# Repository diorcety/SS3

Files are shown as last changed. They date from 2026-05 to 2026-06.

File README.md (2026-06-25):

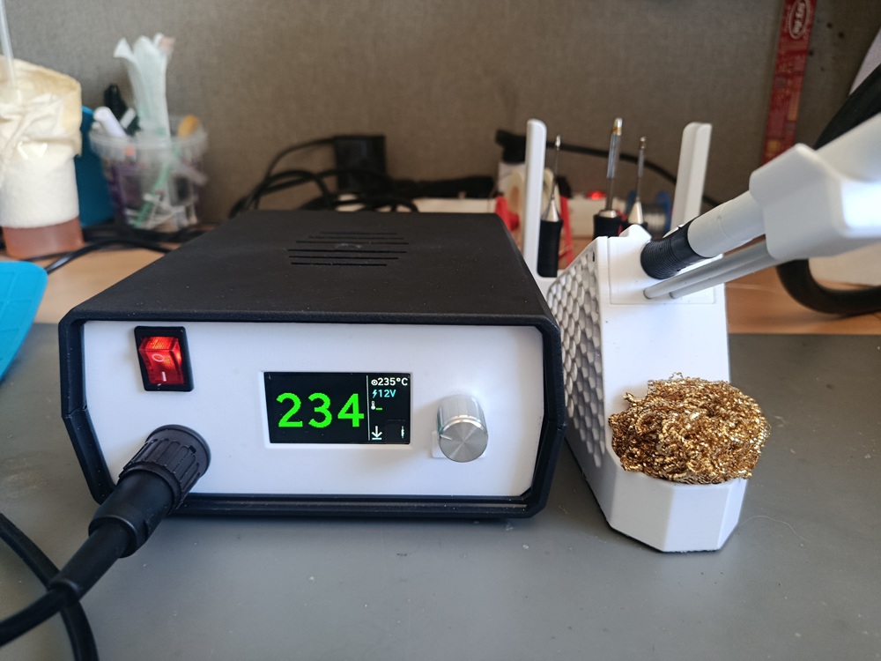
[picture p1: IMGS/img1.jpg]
SS3 Solder Station


# SS3 — Solder Station 3

A DIY Weller-compatible soldering station controller, inspired by the [kair.us Weller WMRP and WMRT compatible soldering station](http://kair.us/projects/weller/index.html).

## Overview

SS3 is a two-board redesign of the kair.us open-source solder station. The key differences from the original are:

- **Transformer-based power supply** instead of SMPS — cleaner, simpler, lower EMI
- **Native 12V and 24V tip support** — handle type is identified by reading a resistor inside the handle via a voltage divider (510Ω for WXUP, 1kΩ for WMRP, 2kΩ for WMRT)
- **MSPM0G1507SRHBR MCU** (Texas Instruments) replacing the PIC16F1788
- **Dual MOSFET back-to-back switching stage** acting as a solid-state triac with minimal conduction losses

## Hardware — Two Boards

### MCU / Display Board
Handles all control logic, ADC measurements, and user interface.

- MSPM0G1507SRHBR microcontroller (default)
  - MSPM0G1505SRHBR can be used for 7-segment display builds
  - MSPM0G1506SRHBR can be used for TFT display builds
  - Switching variant requires updating `device_linker.cmd`
- Onboard ADC for thermocouple sensing (cold-junction compensation is handled inside the handle itself)
- Display support:
  - 4× 7-segment LED display
  - 1.9" TFT color screen

### Power Board
Drives the resistive heating element of the tip.

- Four dual N-MOSFET ICs (8 MOSFETs total), one per heating channel: two channels (left/right) × two voltages (12V/24V), each pair wired back-to-back
- Each pair acts as a solid-state triac equivalent, covering both 12V and 24V channels
- Lower switching losses compared to a traditional triac

## Tip Compatibility

Compatible with Weller active tips using an integrated heater and thermocouple:

- **WMRP** — soldering pen (12V)
- **WMRT** — desoldering tweezers (12V)
- **WXUP** — soldering pen (24V)

## Directory Structure

```
SS3/
├── 3D/       — Stands and handle models (12V and 24V variants; no enclosure provided)
├── PCBS/     — KiCad / Gerber files for both boards, plus KiCad conversions of the
│              original kair.us WMRP and WMRT boards (including mirrored variant for
│              mirrored jack barrels)
├── SIMS/     — LTSpice simulations: zero-cross detection, 3.6V SMPS from half-wave
│              rectifier, and back-to-back N-MOSFET triac equivalent
└── SS3/      — Firmware source (CMake project)
```

## Credits

Based on the open-source [Weller WMRP and WMRT compatible soldering station](http://kair.us/projects/weller/index.html) by kair.us.

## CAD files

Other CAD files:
3D/Stand.f3d
3D/WMRP Handle.f3d
3D/WXUP Handle.f3d

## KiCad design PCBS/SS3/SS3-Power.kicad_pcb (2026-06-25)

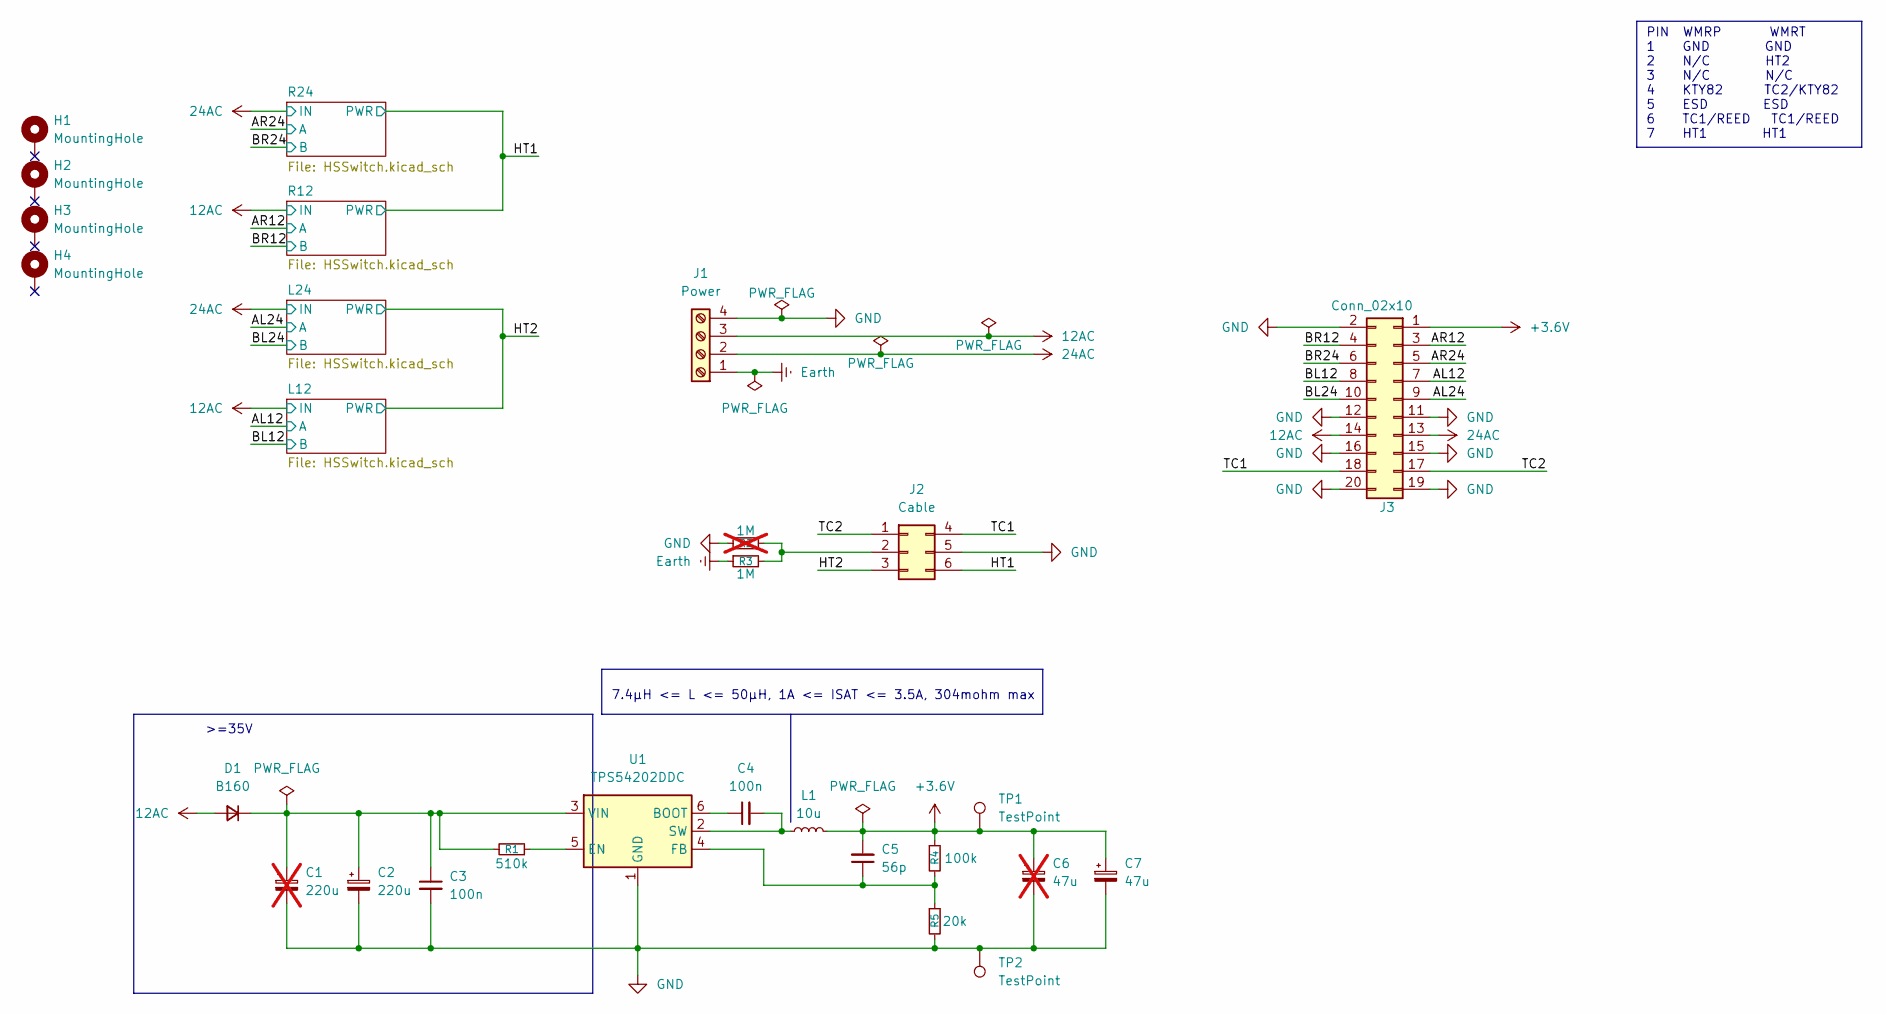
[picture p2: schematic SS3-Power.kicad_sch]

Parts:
C1: 220u; CP_Elec_10x10.5; not fitted
C2: 220u; CP_Elec_10x10.5
C3, C4: 100n; C_0402_1005Metric
C5: 56p; C_0402_1005Metric
C6: 47u; CP_Elec_6.3x5.9; not fitted
C7: 47u; CP_Elec_6.3x5.9
D1: B160; D_SMB
H1, H2, H3, H4: MountingHole; MountingHole_2mm_M1.8_Pad
J1: Power; TerminalBlock_Phoenix_PT-1,5-4-3.5-H_1x04_P3.50mm_Horizontal
J2: Cable; 10127720-061LF
J3: Conn_02x10; BF030-20A-B1-0360
L1: 10u; L_Chilisin_BWVS00606045
R1: 510k; R_0402_1005Metric
R2: 1M; R_0402_1005Metric; not fitted
R3: 1M; R_0402_1005Metric
R4: 100k; R_0402_1005Metric
R5: 20k; R_0402_1005Metric
TP1, TP2: TestPoint; TestPoint_THTPad_D2.0mm_Drill1.0mm
U1: TPS54202DDC; SOT-23-6

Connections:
12AC: D1.2 (A), J1.3, J3.14; also elsewhere on the board
24AC: J1.2, J3.13; also elsewhere on the board
+3.6V: C5.2, C6.1, C7.1, J3.1, L1.2, R4.1, TP1.1 (1_1)
/AL12: J3.7; also elsewhere on the board
/AL24: J3.9; also elsewhere on the board
/AR12: J3.3; also elsewhere on the board
/AR24: J3.5; also elsewhere on the board
/BL12: J3.8; also elsewhere on the board
/BL24: J3.10; also elsewhere on the board
/BR12: J3.4; also elsewhere on the board
/BR24: J3.6; also elsewhere on the board
/HT1: J2.6; also elsewhere on the board
/HT2: J2.3; also elsewhere on the board
/TC1: J2.4, J3.18
/TC2: J2.1, J3.17
Earth: J1.1, R3.1
GND: C1.2, C2.2, C3.2, C6.2, C7.2, J1.4, J2.5, J3.2, J3.11, J3.12, J3.15, J3.16, J3.19, J3.20, R2.2, R5.2, TP2.1 (1_1), U1.1 (GND); also elsewhere on the board
unnamed: C1.1, C2.1, C3.1, D1.1 (K), R1.2, U1.3 (VIN)
unnamed: J2.2, R2.1, R3.2
unnamed: C4.1, U1.6 (BOOT)
unnamed: R1.1, U1.5 (EN)
unnamed: C5.1, R4.2, R5.1, U1.4 (FB)
unnamed: C4.2, L1.1, U1.2 (SW)

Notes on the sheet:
PIN WMRP WMRT 1 GND GND 2 N/C HT2 3 N/C N/C 4 KTY82 TC2/KTY82 5 ESD ESD 6 TC1/REED TC1/REED 7 HT1 HT1
>=35V
7.4μH <= L <= 50μH, 1A <= ISAT <= 3.5A, 304mohm max

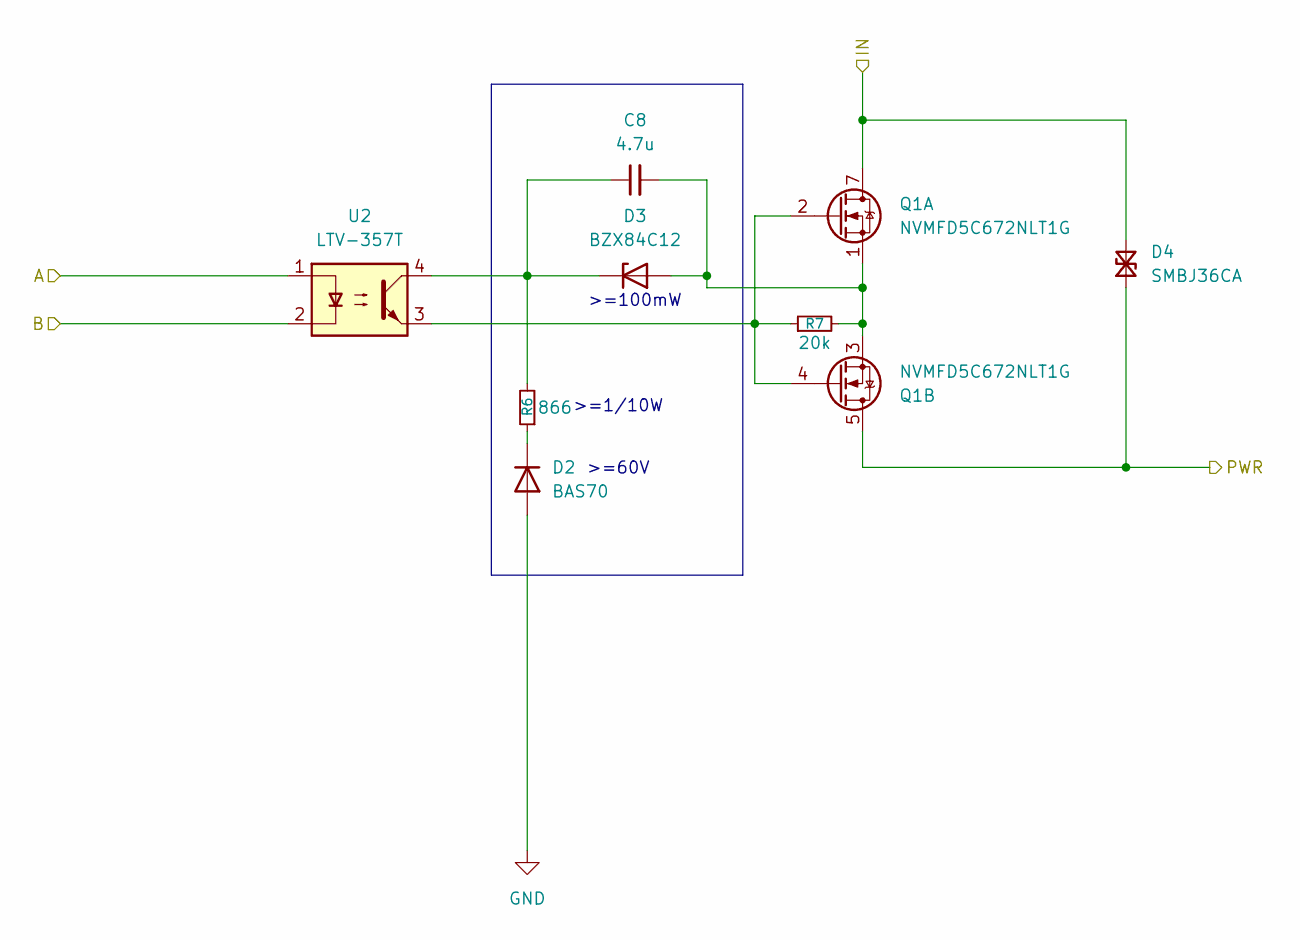
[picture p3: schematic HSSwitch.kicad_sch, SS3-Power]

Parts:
C8: 4.7u; C_0805_2012Metric
D2: BAS70; SOT-23
D3: BZX84C12; SOT-23
D4: SMBJ36CA; D_SMB
Q1: NVMFD5C672NLT1G; Mouser Part Number 863-NVMFD5C672NLT1G
R6: 866; R_0805_2012Metric
R7: 20k; R_0402_1005Metric
U2: LTV-357T; SO-4_4.4x3.6mm_P2.54mm

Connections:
24AC: D4.2 (A2), Q1.7, Q1.8 (D), Q1.9 (D), Q1.10 (D), Q1.11 (D); also elsewhere on the board
/AR24: U2.1; also elsewhere on the board
/BR24: U2.2; also elsewhere on the board
/HT1: D4.1 (A1), Q1.5, Q1.6 (D), Q1.12 (D), Q1.13 (D), Q1.14 (D); also elsewhere on the board
GND: D2.1 (A); also elsewhere on the board
unnamed: D2.3 (K), R6.1
unnamed: C8.2, D3.1 (A), Q1.1, Q1.3, R7.2
unnamed: C8.1, D3.3 (K), R6.2, U2.4
unnamed: Q1.2, Q1.4, R7.1, U2.3

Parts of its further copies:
C9, C10, C11: 4.7u; C_0805_2012Metric
D5, D8, D11: BAS70; SOT-23
D6, D9, D12: BZX84C12; SOT-23
D7, D10, D13: SMBJ36CA; D_SMB
Q2, Q3, Q4: NVMFD5C672NLT1G; Mouser Part Number 863-NVMFD5C672NLT1G
R8, R10, R12: 866; R_0805_2012Metric
R9, R11, R13: 20k; R_0402_1005Metric
U3, U4, U5: LTV-357T; SO-4_4.4x3.6mm_P2.54mm

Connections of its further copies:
12AC: D7.2 (A2), D13.2 (A2), Q2.7, Q2.8 (D), Q2.9 (D), Q2.10 (D), Q2.11 (D), Q4.7, Q4.8 (D), Q4.9 (D), Q4.10 (D), Q4.11 (D); also elsewhere on the board
24AC: D10.2 (A2), Q3.7, Q3.8 (D), Q3.9 (D), Q3.10 (D), Q3.11 (D); also elsewhere on the board
/AL12: U5.1; also elsewhere on the board
/AL24: U4.1; also elsewhere on the board
/AR12: U3.1; also elsewhere on the board
/BL12: U5.2; also elsewhere on the board
/BL24: U4.2; also elsewhere on the board
/BR12: U3.2; also elsewhere on the board
/HT1: D7.1 (A1), Q2.5, Q2.6 (D), Q2.12 (D), Q2.13 (D), Q2.14 (D); also elsewhere on the board
/HT2: D10.1 (A1), D13.1 (A1), Q3.5, Q3.6 (D), Q3.12 (D), Q3.13 (D), Q3.14 (D), Q4.5, Q4.6 (D), Q4.12 (D), Q4.13 (D), Q4.14 (D); also elsewhere on the board
GND: D5.1 (A), D8.1 (A), D11.1 (A); also elsewhere on the board
unnamed: D5.3 (K), R8.1
unnamed: C9.2, D6.1 (A), Q2.1, Q2.3, R9.2
unnamed: C9.1, D6.3 (K), R8.2, U3.4
unnamed: D8.3 (K), R10.1
unnamed: C10.2, D9.1 (A), Q3.1, Q3.3, R11.2
unnamed: C10.1, D9.3 (K), R10.2, U4.4
unnamed: D11.3 (K), R12.1
unnamed: C11.2, D12.1 (A), Q4.1, Q4.3, R13.2
unnamed: C11.1, D12.3 (K), R12.2, U5.4
unnamed: Q2.2, Q2.4, R9.1, U3.3
unnamed: Q3.2, Q3.4, R11.1, U4.3
unnamed: Q4.2, Q4.4, R13.1, U5.3

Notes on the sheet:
>=100mW
>=60V
>=1/10W

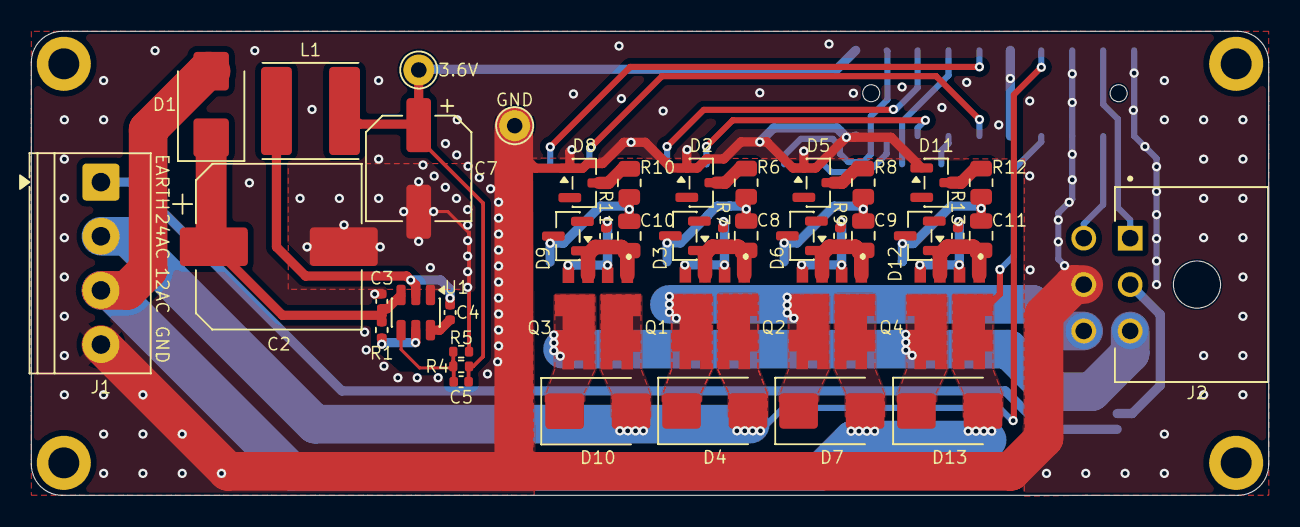
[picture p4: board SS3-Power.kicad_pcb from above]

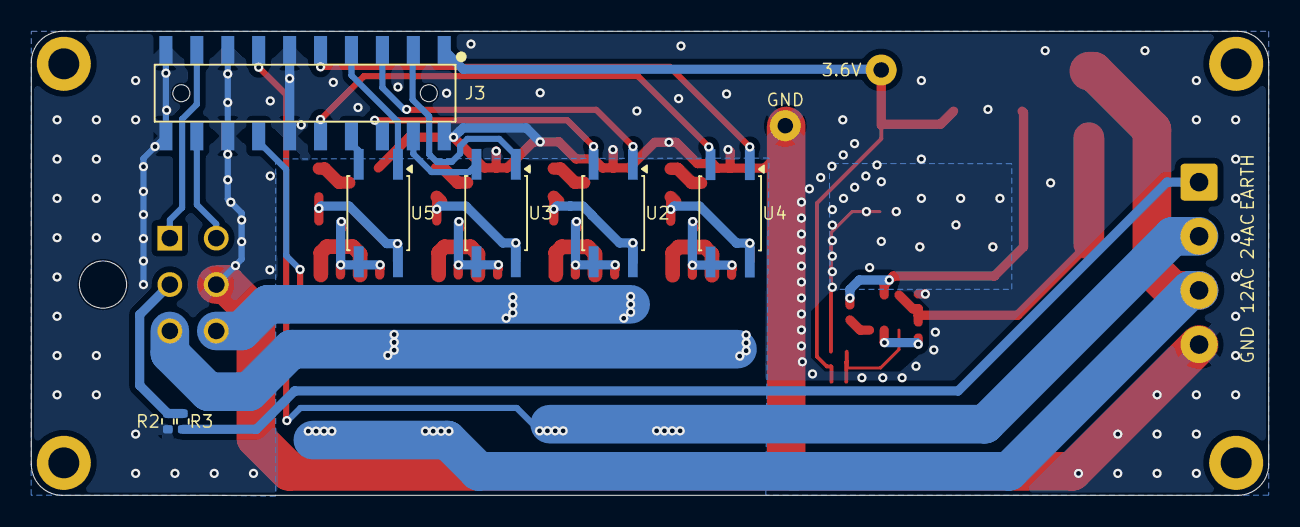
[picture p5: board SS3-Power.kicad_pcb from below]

Board: 2 copper layers, 80.0 x 30.0 mm, 54 parts (7 on the bottom side), 39 nets.

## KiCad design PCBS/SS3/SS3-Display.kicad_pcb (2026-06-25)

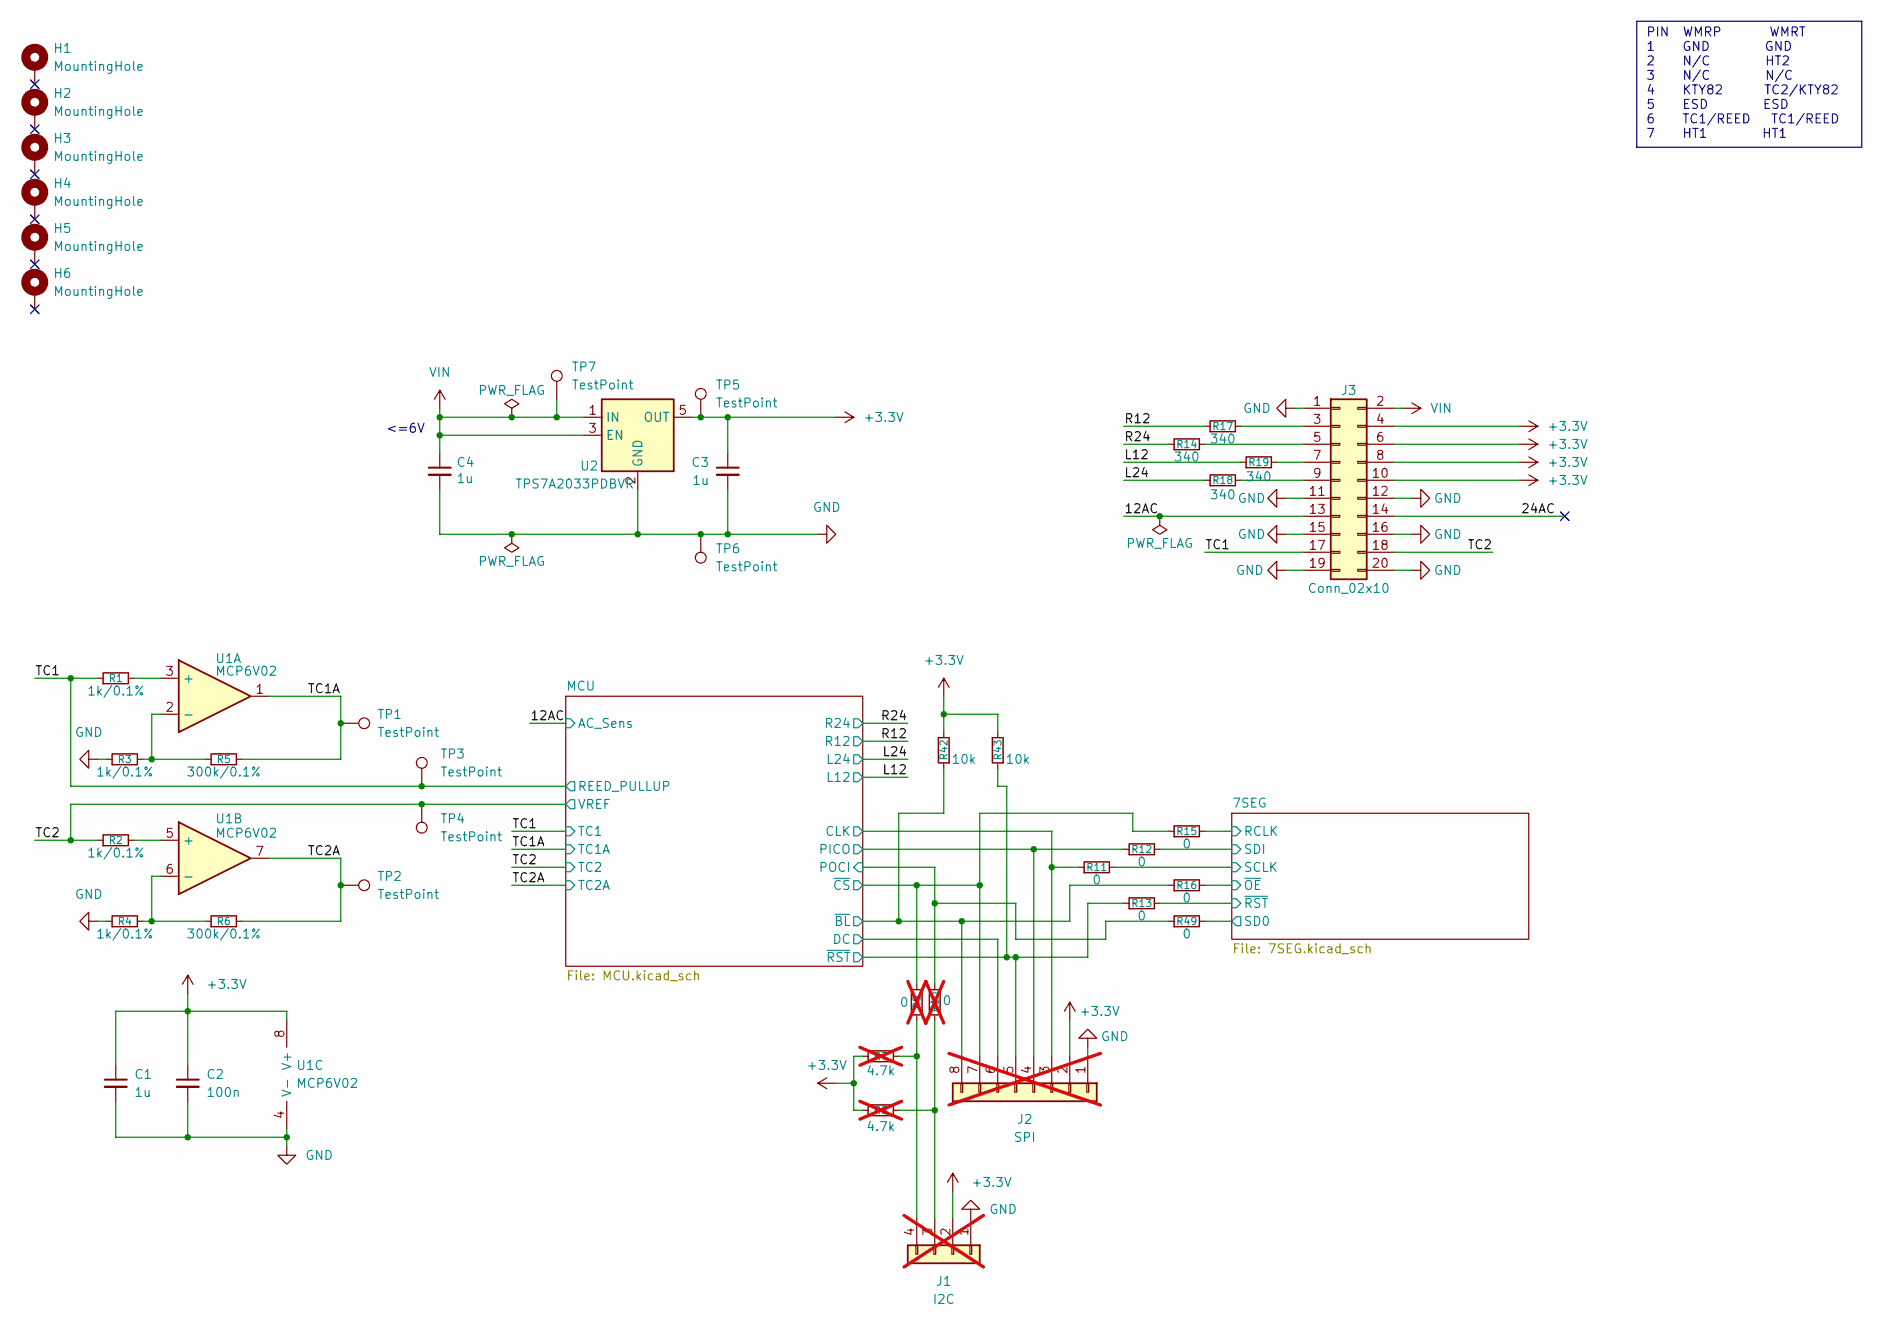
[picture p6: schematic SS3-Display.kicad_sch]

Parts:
C1, C3, C4: 1u; C_0402_1005Metric
C2: 100n; C_0402_1005Metric
H1, H2, H3, H4, H5, H6: MountingHole; MountingHole_2mm_M1.8_Pad
J1: I2C; PinHeader_1x04_P2.54mm_Vertical; not fitted
J2: SPI; PinHeader_1x08_P2.54mm_Vertical; not fitted
J3: Conn_02x10; BF100-20-A-D-1-0640
R1, R2, R3, R4: 1k/0.1%; R_0402_1005Metric
R5, R6: 300k/0.1%; R_0402_1005Metric
R7, R8: 4.7k; R_0402_1005Metric; not fitted
R9, R10: 0; R_0402_1005Metric; not fitted
R11, R12, R13, R15, R16, R49: 0; R_0402_1005Metric
R14, R17, R18, R19: 340; R_0402_1005Metric
R42, R43: 10k; R_0402_1005Metric
TP1, TP2, TP3, TP4, TP5, TP6, TP7: TestPoint; TestPoint_THTPad_D2.0mm_Drill1.0mm
U1: MCP6V02; SOIC-8_3.9x4.9mm_P1.27mm
U2: TPS7A2033PDBVR; SOT-23-5

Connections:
+3.3V: C1.1, C2.1, C3.1, J1.2, J2.2, J3.4, J3.6, J3.8, J3.10, R7.2, R8.2, R42.2, R43.2, TP5.1 (1_1), U1.8 (V+), U2.5 (OUT); also elsewhere on the board
/7SEG/RCLK: R15.2; also elsewhere on the board
/7SEG/SCLK: R11.2; also elsewhere on the board
/7SEG/SD0: R49.2; also elsewhere on the board
/7SEG/SDI: R12.2; also elsewhere on the board
/7SEG/~OE: R16.2; also elsewhere on the board
/7SEG/~RST: R13.2; also elsewhere on the board
/12AC: J3.13; also elsewhere on the board
/24AC: J3.14
/L12: R19.1; also elsewhere on the board
/L24: R18.1; also elsewhere on the board
/MCU/CLK: J2.3, R11.1; also elsewhere on the board
/MCU/DC: J2.6; also elsewhere on the board
/MCU/PICO: J2.4, R12.1; also elsewhere on the board
/MCU/POCI: R10.1, R49.1; also elsewhere on the board
/MCU/~BL: J2.8, R16.1, R42.1; also elsewhere on the board
/MCU/~CS: J2.7, R9.1, R15.1; also elsewhere on the board
/MCU/~RST: J2.5, R13.1, R43.1; also elsewhere on the board
/R12: R17.1; also elsewhere on the board
/R24: R14.1; also elsewhere on the board
/TC1: J3.17, R1.1, TP3.1 (1_1); also elsewhere on the board
/TC1A: R5.2, TP1.1 (1_1), U1.1; also elsewhere on the board
/TC2: J3.18, R2.1, TP4.1 (1_1); also elsewhere on the board
/TC2A: R6.2, TP2.1 (1_1), U1.7; also elsewhere on the board
GND: C1.2, C2.2, C3.2, C4.2, J1.1, J2.1, J3.1, J3.11, J3.12, J3.15, J3.16, J3.19, J3.20, R3.1, R4.1, TP6.1 (1_1), U1.4 (V-), U2.2 (GND); also elsewhere on the board
unnamed: J1.3, R8.1, R10.2
unnamed: J1.4, R7.1, R9.2
unnamed: J3.3, R17.2
unnamed: J3.5, R14.2
unnamed: J3.7, R19.2
unnamed: J3.9, R18.2
unnamed: R1.2, U1.3 (+)
unnamed: R3.2, R5.1, U1.2 (-)
unnamed: R2.2, U1.5 (+)
unnamed: R4.2, R6.1, U1.6 (-)
VIN: C4.1, J3.2, TP7.1 (1_1), U2.1 (IN), U2.3 (EN)

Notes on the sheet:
<=6V
PIN WMRP WMRT 1 GND GND 2 N/C HT2 3 N/C N/C 4 KTY82 TC2/KTY82 5 ESD ESD 6 TC1/REED TC1/REED 7 HT1 HT1

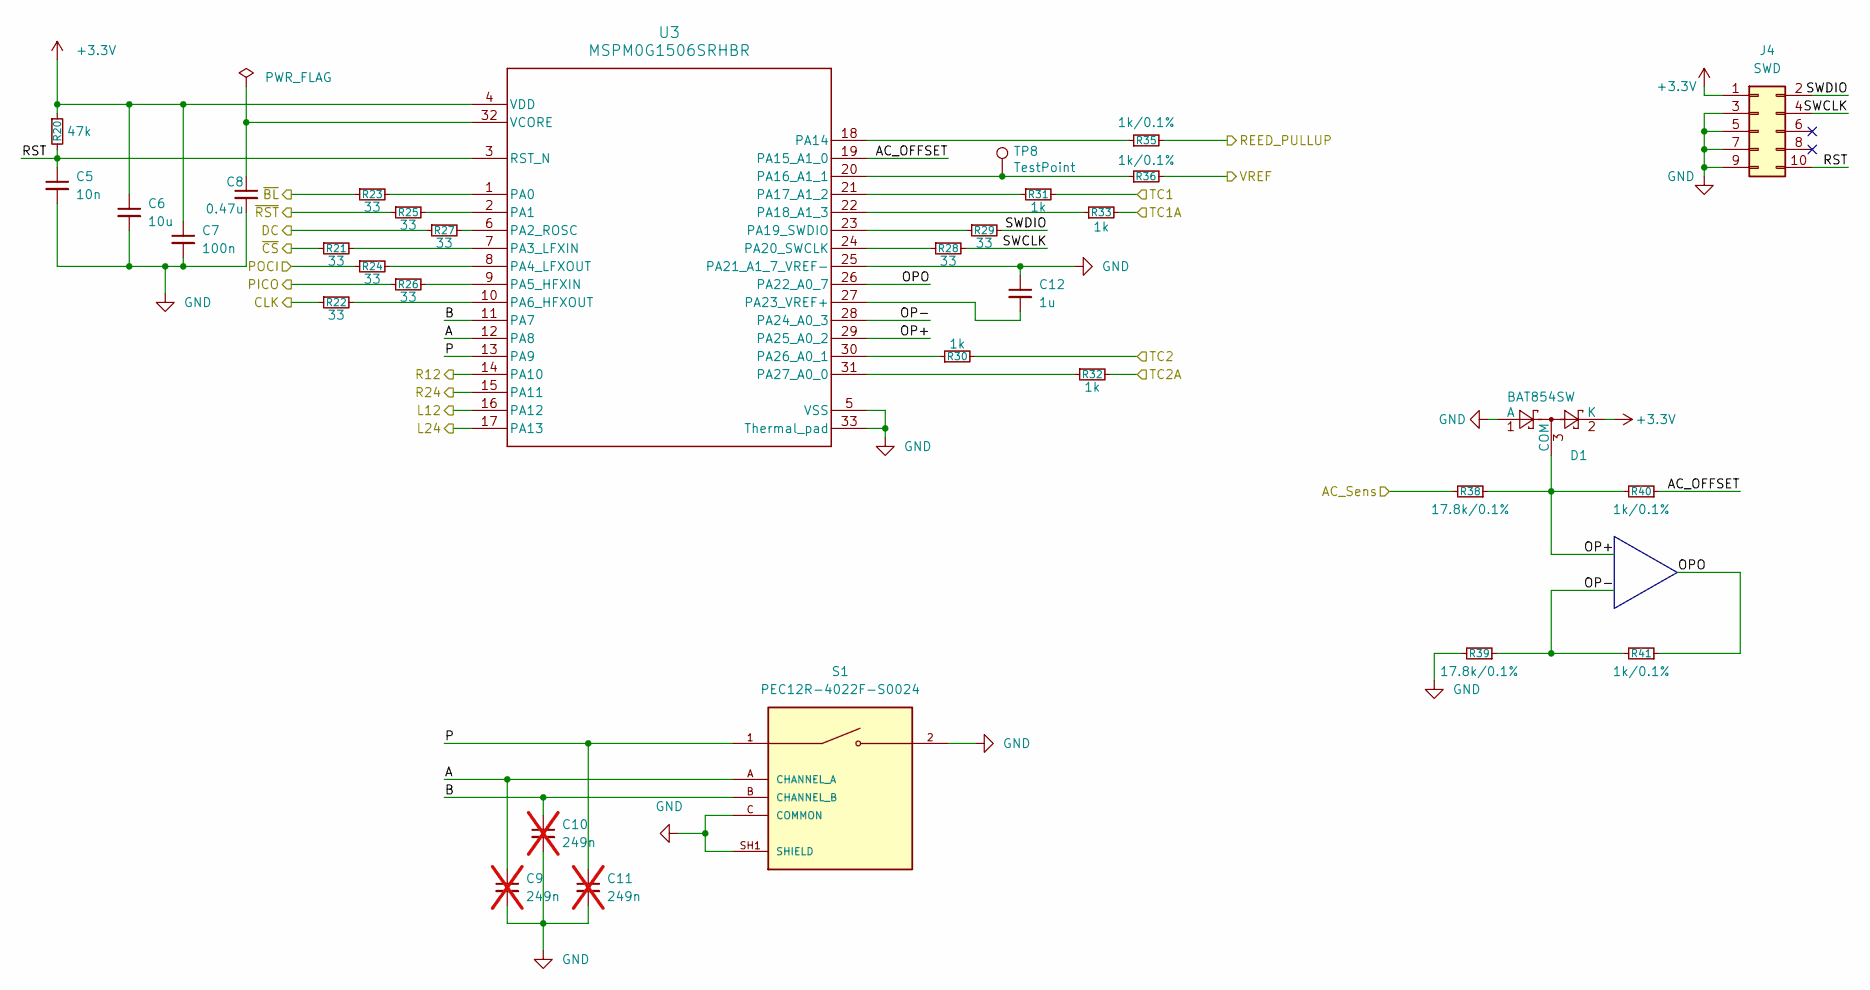
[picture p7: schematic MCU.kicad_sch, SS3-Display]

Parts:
C5: 10n; C_0402_1005Metric
C6: 10u; C_0603_1608Metric
C7: 100n; C_0402_1005Metric
C8: 0.47u; C_0402_1005Metric
C9, C10, C11: 249n; C_0402_1005Metric; not fitted
C12: 1u; C_0402_1005Metric
D1: BAT854SW; SOT-323_SC-70
J4: SWD; 20021511-00010T4LF
R20: 47k; R_0402_1005Metric
R21, R22, R23, R24, R25, R26, R27, R28, R29: 33; R_0402_1005Metric
R30, R31, R32, R33: 1k; R_0402_1005Metric
R35, R36, R40, R41: 1k/0.1%; R_0402_1005Metric
R38, R39: 17.8k/0.1%; R_0402_1005Metric
S1: PEC12R-4022F-S0024; PARTREV 07/21; DigiKey_Part_Number PEC12R-4022F-S0024-ND
TP8: TestPoint; TestPoint_THTPad_D2.0mm_Drill1.0mm
U3: MSPM0G1506SRHBR; VQFN-32-1EP_5x5mm_P0.5mm_EP3.5x3.5mm_ThermalVias

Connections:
+3.3V: C6.1, C7.1, D1.2 (K), J4.1, R20.1, U3.4 (VDD); also elsewhere on the board
/12AC: R38.2; also elsewhere on the board
/L12: U3.16 (PA12); also elsewhere on the board
/L24: U3.17 (PA13); also elsewhere on the board
/MCU/A: C9.1, S1.A (CHANNEL_A), U3.12 (PA8)
/MCU/AC_OFFSET: R40.1, U3.19 (PA15_A1_0)
/MCU/B: C10.1, S1.B (CHANNEL_B), U3.11 (PA7)
/MCU/CLK: R22.1; also elsewhere on the board
/MCU/DC: R27.1; also elsewhere on the board
/MCU/OP+: D1.3 (COM), R38.1, R40.2, U3.29 (PA25_A0_2)
/MCU/OP-: R39.1, R41.2, U3.28 (PA24_A0_3)
/MCU/OPO: R41.1, U3.26 (PA22_A0_7)
/MCU/P: C11.1, S1.1, U3.13 (PA9)
/MCU/PICO: R26.1; also elsewhere on the board
/MCU/POCI: R24.1; also elsewhere on the board
/MCU/RST: C5.1, J4.10, R20.2, U3.3 (RST_N)
/MCU/SWCLK: J4.4, R28.2
/MCU/SWDIO: J4.2, R29.2
/MCU/~BL: R23.1; also elsewhere on the board
/MCU/~CS: R21.1; also elsewhere on the board
/MCU/~RST: R25.1; also elsewhere on the board
/R12: U3.14 (PA10); also elsewhere on the board
/R24: U3.15 (PA11); also elsewhere on the board
/TC1: R31.2, R35.2; also elsewhere on the board
/TC1A: R33.2; also elsewhere on the board
/TC2: R30.2, R36.2; also elsewhere on the board
/TC2A: R32.2; also elsewhere on the board
GND: C5.2, C6.2, C7.2, C8.2, C9.2, C10.2, C11.2, C12.1, D1.1 (A), J4.3, J4.5, J4.7, J4.9, R39.2, S1.2, S1.C (COMMON), S1.SH1 (SHIELD), S1.SH2 (SHIELD), U3.5 (VSS), U3.25 (PA21_A1_7_VREF-), U3.33 (Thermal_pad); also elsewhere on the board
unnamed: R23.2, U3.1 (PA0)
unnamed: R25.2, U3.2 (PA1)
unnamed: R27.2, U3.6 (PA2_ROSC)
unnamed: R21.2, U3.7 (PA3_LFXIN)
unnamed: R24.2, U3.8 (PA4_LFXOUT)
unnamed: R26.2, U3.9 (PA5_HFXIN)
unnamed: R22.2, U3.10 (PA6_HFXOUT)
unnamed: R35.1, U3.18 (PA14)
unnamed: R36.1, TP8.1 (1_1), U3.20 (PA16_A1_1)
unnamed: R31.1, U3.21 (PA17_A1_2)
unnamed: R33.1, U3.22 (PA18_A1_3)
unnamed: R29.1, U3.23 (PA19_SWDIO)
unnamed: R28.1, U3.24 (PA20_SWCLK)
unnamed: C12.2, U3.27 (PA23_VREF+)
unnamed: R30.1, U3.30 (PA26_A0_1)
unnamed: R32.1, U3.31 (PA27_A0_0)
unnamed: C8.1, U3.32 (VCORE)

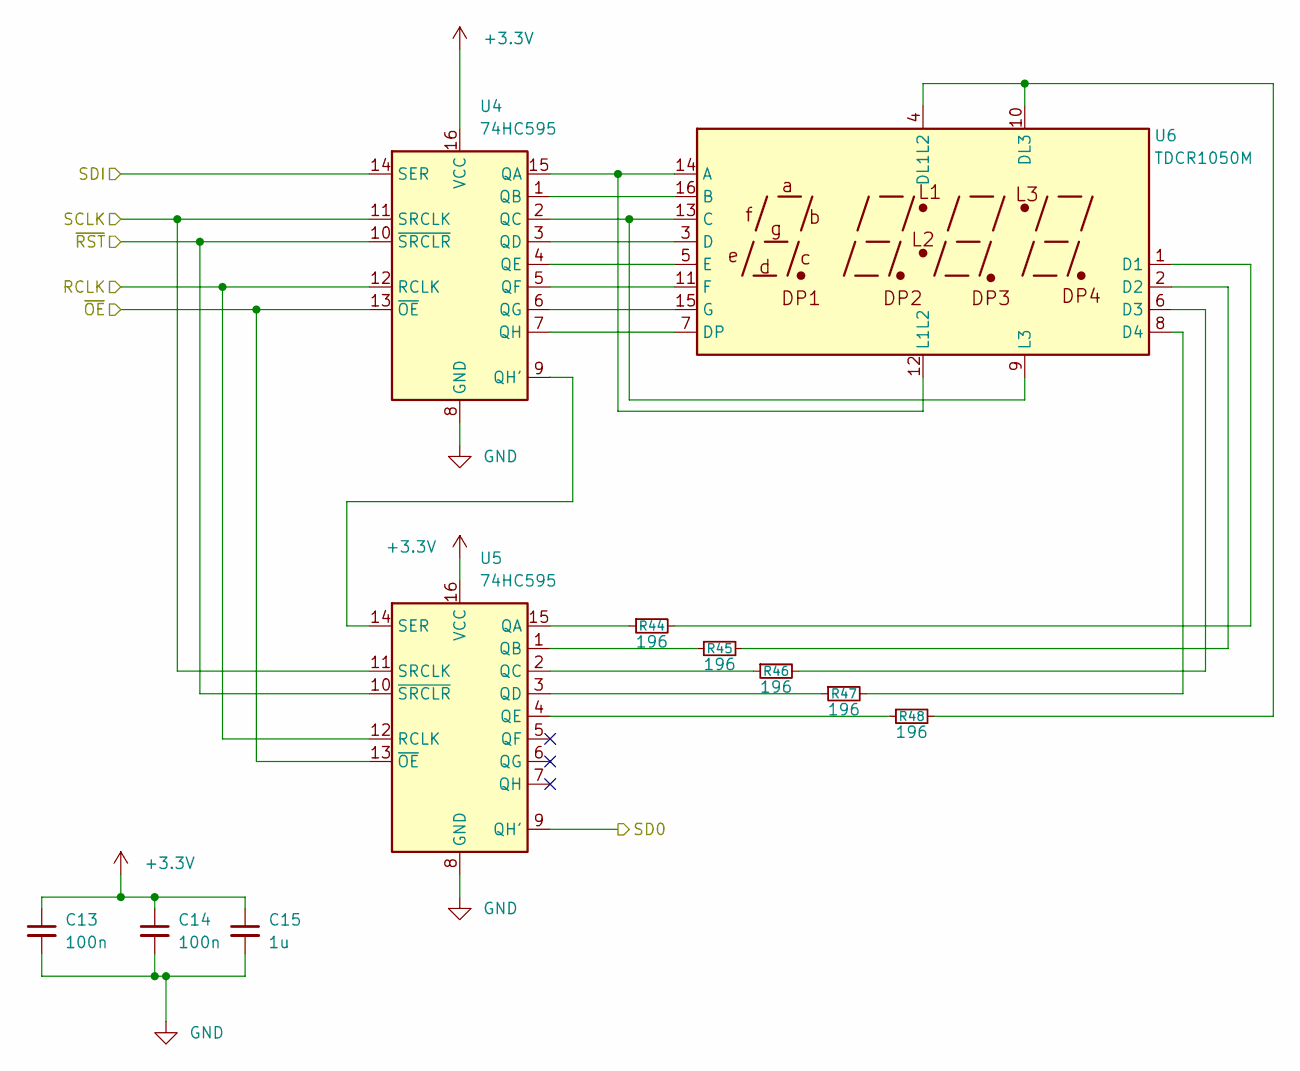
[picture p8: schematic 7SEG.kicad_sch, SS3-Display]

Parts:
C13, C14: 100n; C_0402_1005Metric
C15: 1u; C_0402_1005Metric
R44, R45, R46, R47, R48: 196; R_0402_1005Metric
U4, U5: 74HC595; TSSOP-16_4.4x5mm_P0.65mm
U6: TDCR1050M

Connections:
+3.3V: C13.1, C14.1, C15.1, U4.16 (VCC), U5.16 (VCC); also elsewhere on the board
/7SEG/RCLK: U4.12 (RCLK), U5.12 (RCLK); also elsewhere on the board
/7SEG/SCLK: U4.11 (SRCLK), U5.11 (SRCLK); also elsewhere on the board
/7SEG/SD0: U5.9 (QH'); also elsewhere on the board
/7SEG/SDI: U4.14 (SER); also elsewhere on the board
/7SEG/~OE: U4.13 (~OE), U5.13 (~OE); also elsewhere on the board
/7SEG/~RST: U4.10 (~SRCLR), U5.10 (~SRCLR); also elsewhere on the board
GND: C13.2, C14.2, C15.2, U4.8 (GND), U5.8 (GND); also elsewhere on the board
unnamed: U4.15 (QA), U6.12 (L1L2), U6.14 (A)
unnamed: U4.1 (QB), U6.16 (B)
unnamed: U4.2 (QC), U6.9 (L3), U6.13 (C)
unnamed: U4.3 (QD), U6.3 (D)
unnamed: U4.4 (QE), U6.5 (E)
unnamed: U4.5 (QF), U6.11 (F)
unnamed: U4.6 (QG), U6.15 (G)
unnamed: U4.9 (QH'), U5.14 (SER)
unnamed: U4.7 (QH), U6.7 (DP)
unnamed: R44.1, U5.15 (QA)
unnamed: R45.1, U5.1 (QB)
unnamed: R46.1, U5.2 (QC)
unnamed: R47.1, U5.3 (QD)
unnamed: R48.1, U5.4 (QE)
unnamed: R44.2, U6.1 (D1)
unnamed: R45.2, U6.2 (D2)
unnamed: R46.2, U6.6 (D3)
unnamed: R47.2, U6.8 (D4)
unnamed: R48.2, U6.4 (DL1L2), U6.10 (DL3)

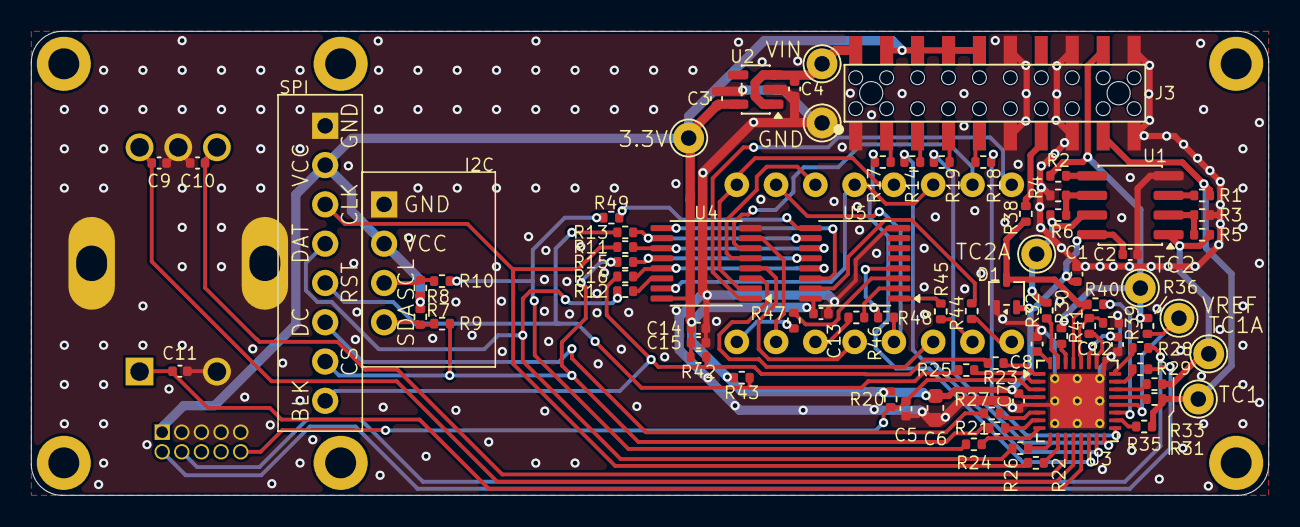
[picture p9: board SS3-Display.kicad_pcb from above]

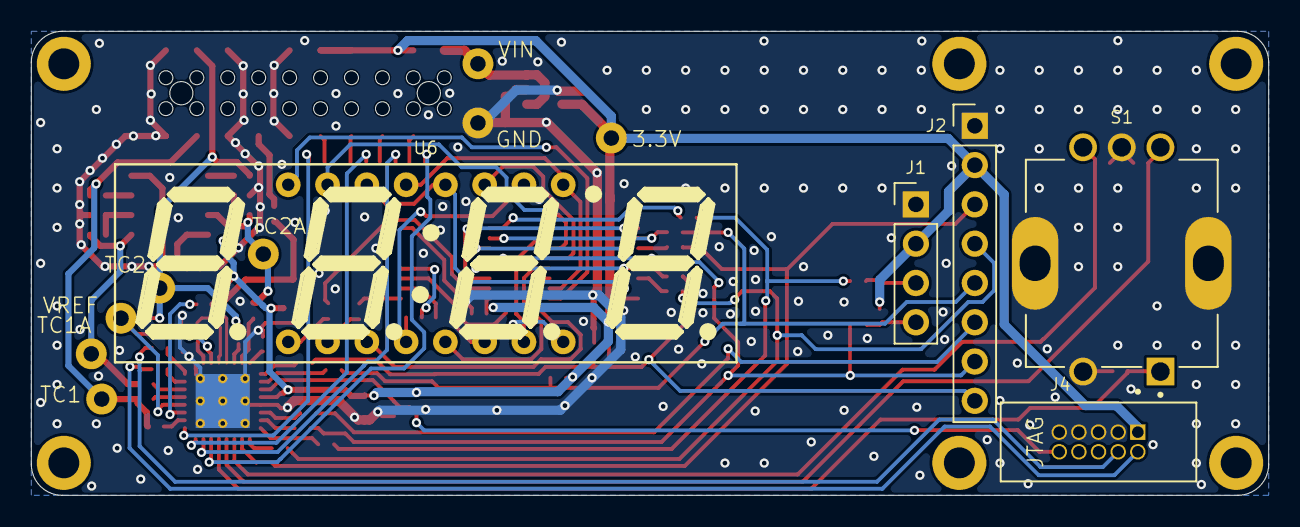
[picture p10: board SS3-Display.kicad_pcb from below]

Board: 2 copper layers, 80.0 x 30.0 mm, 88 parts (5 on the bottom side), 81 nets.

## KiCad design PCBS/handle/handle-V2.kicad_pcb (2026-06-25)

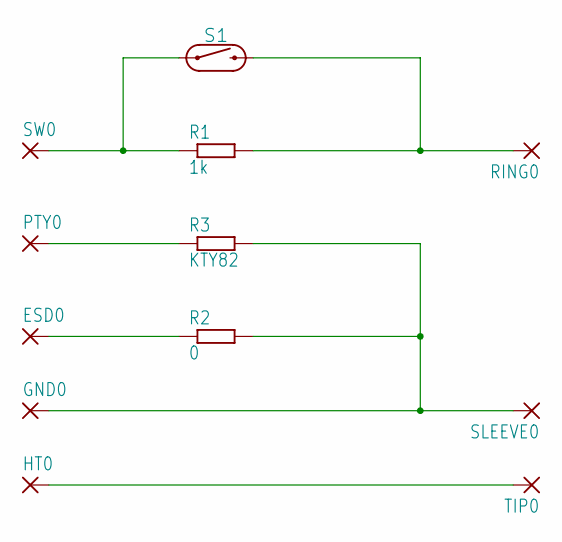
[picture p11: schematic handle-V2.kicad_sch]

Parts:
ESD0: SMD2; SMD1,27-2,54
GND0: WIREPADSMD5-1,8; 5-1,8
HT0: WIREPADSMD5-1,8; 5-1,8
PTY0: SMD2; SMD1,27-2,54
R1: 1k; R0805
R2: 0; R0805
R3: KTY82; R0805
RING0: WIREPADSMD5-1,8; 5-1,8
S1: REED_SWITCH-PTH-INSULATED; REED_SWITCH_PLASTIC
SLEEVE0: WIREPADSMD5-1,8; 5-1,8
SW0: SMD2; SMD1,27-2,54
TIP0: WIREPADSMD5-1,8; 5-1,8

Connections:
ESD: ESD0.1, R2.1
GND: GND0.1, R2.2, R3.2, SLEEVE0.1
HEATHER: HT0.1, TIP0.1
unnamed: R1.2, RING0.1, S1.P$2 (2)
PTC: PTY0.1, R3.1
SW: R1.1, S1.P$1 (1), SW0.1

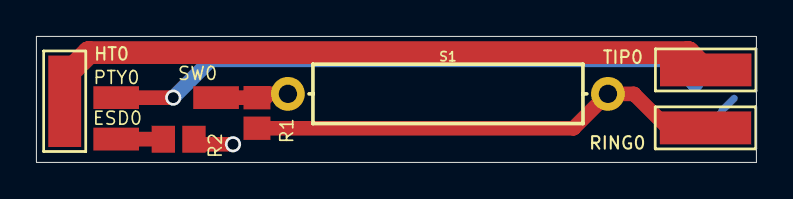
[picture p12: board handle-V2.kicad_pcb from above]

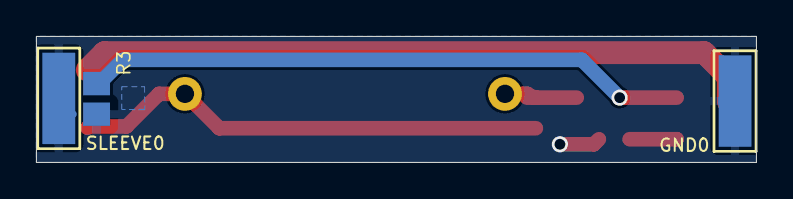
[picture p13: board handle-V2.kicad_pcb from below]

Board: 2 copper layers, 40.0 x 7.0 mm, 12 parts (3 on the bottom side), 6 nets.

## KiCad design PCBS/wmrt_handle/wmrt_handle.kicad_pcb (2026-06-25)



Board: 2 copper layers, 22.0 x 9.5 mm, 12 parts (2 on the bottom side), 8 nets.

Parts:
R1: 2k; R0805
R2: KTY82/110; SOT-23
R3: 0R; R0805
S1: RI80SMDM-0510-J1; RI-80_SMDM_J-1
U$1: JAKA_LOGO_SILK_NANO; JAKA_SILK_NANO
W1, W2, W4, W5, W6, W7: TESTPOINTTH_1MM3_ROUND; P1-13-R
X1: 09-9792-20-05; 09-9792-20-05_BINDER

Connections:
GND: R3.1, W1.TP, X1.3
unnamed: R2.2, W4.TP
unnamed: R2.1, X1.4
unnamed: R1.2, S1.2, W6.TP
unnamed: R1.1, S1.1, X1.2
unnamed: W2.TP, X1.5
unnamed: W7.TP, X1.1
unnamed: R3.2, W5.TP

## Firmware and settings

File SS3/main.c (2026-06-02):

#include "main.h"
#include "acquisition.h"
#include "adc.h"
#include "board.h"
#include "button.h"
#include "configuration.h"
#include "display.h"
#include "heat.h"
#include "iron.h"
#if defined(USE_SEG7)
#include "seg7.h"
#endif
#if defined(USE_ST7789)
#include "st7789.h"
#endif
#include "tick.h"
#include "tip.h"
#include "zcd.h"

/*********************************************************************************************************************
 *                                                                                                                   *
 *                                                 FUNCTIONS                                                         *
 *                                                                                                                   *
 *********************************************************************************************************************/

static void init(void) {
  //
  // Configuration first
  //
  configuration_init();
  configuration_load();

  zcd_init();
  adc_init();
  button_init();

  acquisition_init();
  tip_init();
  heat_init();

  iron_init();
  display_init();
#if defined(USE_SEG7)
  seg7_init();
#endif
#if defined(USE_ST7789)
  st7789_init();
#endif
}

static void loop(void) {
#ifndef NO_WDG
  DL_WWDT_restart(Watchdog_INST);
#endif

  // Inputs part
  zcd_loop();
  adc_loop();
  button_loop();

  // Process part
  acquisition_loop();
  tip_loop();
  heat_loop();

  // Outputs part
  iron_loop();
  display_loop();
#if defined(USE_SEG7)
  seg7_loop();
#endif
#if defined(USE_ST7789)
  st7789_loop();
#endif

  // Don't freeze during a tricky moment
  if (iron_is_standby()) {
#if !defined(NO_EEPROM_SAVE)
    configuration_loop();
#endif
  }
}

int main(void) {
  SYSCFG_DL_init();

  // Can't be set by default in syscfg
  DL_GPIO_disableOutput(Other_PORT, Other_REED_PULLUP_PIN);
  DL_OPA_setOutputPinState(SecondVRef_INST, OA_CFG_OUTPIN_DISABLED);

  // Initialize SysTickTimer: Don't use cortex systick based on MCLK.
  // The imprecision of PLL leads to incorrect values
  NVIC_ClearPendingIRQ(SysTickTimer_INST_INT_IRQN);
  NVIC_EnableIRQ(SysTickTimer_INST_INT_IRQN);
  DL_TimerA_startCounter(SysTickTimer_INST);

  init();

  for (;;) {
    loop();
  }
}

//
// Interrupt handlers
//

void SysTickTimer_INST_IRQHandler(void) { systick_inc(); }

// Dispatch  GROUP0 interrupt to fake interrupt handlers
void PowerProtection_IRQHandler(void);
void GROUP0_IRQHandler(void) { PowerProtection_IRQHandler(); }

// Dispatch  GROUP1 interrupt to fake interrupt handlers
void ZCD_INST_IRQHandler(void);
void Buttons_INST_IRQHandler(void);
void GROUP1_IRQHandler(void) {
  ZCD_INST_IRQHandler();
  Buttons_INST_IRQHandler();
}

//
// Error handlers
//
void HardFault_Handler(void) { ERROR_HANDLER(); }

void NMI_Handler(void) { ERROR_HANDLER(); }

void iron_set_output(uint32_t value);
void error_handler(void) {
  iron_set_output(0);
  __disable_irq();
  for (;;) {
  }
}

#ifdef NO_WDG

//
// Bypass watchdog init procedures
//

void SYSCFG_DL_Watchdog_init(void) {}

void SYSCFG_DL_PowerProtection_init(void) {}
#endif

void __cxa_pure_virtual(void) { ERROR_HANDLER(); }

extern void CORU_ASSERT(bool valid) {
  if (!valid) {
    ERROR_HANDLER();
  }
}

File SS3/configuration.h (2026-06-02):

#ifndef CONFIGURATION_H_
#define CONFIGURATION_H_

#include <stdbool.h>

/*********************************************************************************************************************
 *                                                                                                                   *
 *                                                 CONSTANTS                                                         *
 *                                                                                                                   *
 *********************************************************************************************************************/

static const int CONFIGURATION_SAVE_DELAY = 5000;

// Assign some 'factory default' values to use when run for the first time
// These are also used if any of the parameters stored in eeprom are outside
// of valid range
static const int SETPOINT_DEFAULT = 240;
static const int SETBACK_DEFAULT = 120;
static const int SETBACK_DELAY_DEFAULT = 60;  // in seconds
static const int STANDBY_DELAY_DEFAULT = 180; // in seconds
static const int TEMPERATURE_OFFSET_DEFAULT = 0;
static const int REFERENCE_DEFAULT = 2500;
static const int STEP_SIZE_DEFAULT = 5;
static const int TEMPERATURE_UNIT_DEFAULT = 0;
static const int POOR_MODE_DEFAULT = 0;
static const int MAX_DUTY_DEFAULT = 45;  // 45%
static const int IDLE_DUTY_DEFAULT = 15; // Idle detection from duty cycle off as default

// Assign sane / safe limits to the above parameters
static const int SETPOINT_MIN = 100;
static const int SETPOINT_MAX = 450;
static const int SETBACK_MIN = SETPOINT_MIN;
static const int SETBACK_MAX = SETPOINT_MAX;
static const int SETBACK_DELAY_MIN = 0;
static const int SETBACK_DELAY_MAX = 3600;
static const int STANDBY_DELAY_MIN = 0;
static const int STANDBY_DELAY_MAX = 3600;
static const int TEMPERATURE_OFFSET_MIN = -40;
static const int TEMPERATURE_OFFSET_MAX = 40;
static const int REFERENCE_MIN = 2450;
static const int REFERENCE_MAX = 2550; // max. tolerance is 2% of 2.500
static const int STEP_SIZE_MIN = 1;
static const int STEP_SIZE_MAX = 10;
static const int TEMPERATURE_UNIT_MIN = 0;
static const int TEMPERATURE_UNIT_MAX = 1;
static const int POOR_MODE_MIN = 0;
static const int POOR_MODE_MAX = 1;
static const int MAX_DUTY_MAX = 60;
static const int MAX_DUTY_MIN = 10;
static const int IDLE_DUTY_MIN = 0;
static const int IDLE_DUTY_MAX = 75;

static const int DUTY_BASE = 100;

static const int FW_VERSION = 1;

static const int KTY_FALLBACK = 30;

typedef enum {
  TEMPERATURE_UNIT_C,
  TEMPERATURE_UNIT_F
} TemperatureUnit;

/*********************************************************************************************************************
 *                                                                                                                   *
 *                                                   DATA                                                            *
 *                                                                                                                   *
 *********************************************************************************************************************/

extern int setpoint;
extern int setback;
extern int setback_delay;
extern int standby_delay;
extern int temperature_offset;
extern int reference;
extern int step_size;
extern int temperature_unit;
extern int poor_mode;
extern int max_duty;
extern int idle_duty;

/*********************************************************************************************************************
 *                                                                                                                   *
 *                                                FUNCTIONS                                                          *
 *                                                                                                                   *
 *********************************************************************************************************************/

void configuration_init(void);
bool configuration_load(void);
void configuration_save(void);
void configuration_loop(void);

#endif // CONFIGURATION_H_

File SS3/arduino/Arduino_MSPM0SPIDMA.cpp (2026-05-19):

#include "Arduino_MSPM0SPIDMA.h"

#if defined(USE_ST7789)

/**
 * @brief Arduino_MSPM0SPIDMA Constructor
 */
Arduino_MSPM0SPIDMA::Arduino_MSPM0SPIDMA(SPI_Regs *spi_inst, int8_t dma_tx_ch, GPIO_Regs *dcPort, uint32_t dcPin,
                                         GPIO_Regs *csPort, uint32_t csPin)
    : _spi_inst(spi_inst), _dma_tx_ch(dma_tx_ch), _dcPort(dcPort), _dcPin(dcPin), _csPort(csPort), _csPin(csPin) {
  (void)(_dma_tx_ch);
}

/**
 * @brief begin
 */
bool Arduino_MSPM0SPIDMA::begin(int32_t speed, int8_t dataMode) {
  (void)(speed);
  (void)(dataMode);

  DC_HIGH();
  CS_HIGH();

  return true;
}

void Arduino_MSPM0SPIDMA::beginWrite() {
  _data_buf_bit_idx = 0;
  _buffer[0] = 0;

  DC_HIGH();
  CS_LOW();
}

void Arduino_MSPM0SPIDMA::endWrite() {
  if (_data_buf_bit_idx > 0) {
    flush_data_buf();
  }
  CS_HIGH();
}

void Arduino_MSPM0SPIDMA::writeCommand(uint8_t c) {
  if (_dcPort == nullptr) // 9-bit SPI
  {
    WRITE9BIT(c);
  } else {
    if (_data_buf_bit_idx > 0) {
      flush_data_buf();
    }

    DC_LOW();

    _spi_tran_length = 8;
    _spi_tran_tx_data[0] = c;
    _spi_tran_use_txdata = true;

    POLL_START();
    POLL_END();

    DC_HIGH();
  }
}

void Arduino_MSPM0SPIDMA::writeCommand16(uint16_t c) {
  if (_dcPort == nullptr) // 9-bit SPI
  {
    _data16.value = c;
    WRITE9BIT(_data16.msb);
    WRITE9BIT(_data16.lsb);
  } else {
    if (_data_buf_bit_idx > 0) {
      flush_data_buf();
    }

    DC_LOW();

    _spi_tran_length = 16;
    MSB_16_SET(_spi_tran_tx_data[0], c);
    _spi_tran_use_txdata = true;

    POLL_START();
    POLL_END();

    DC_HIGH();
  }
}

void Arduino_MSPM0SPIDMA::writeCommandBytes(uint8_t *data, uint32_t len) {
  if (_dcPort == nullptr) // 9-bit SPI
  {
    while (len--) {
      WRITE9BIT(*data++);
    }
  } else {
    DC_LOW();
    while (len--) {
      WRITE8BIT(*data++);
    }
    DC_HIGH();
  }
}

void Arduino_MSPM0SPIDMA::write(uint8_t d) {
  if (_dcPort == nullptr) // 9-bit SPI
  {
    WRITE9BIT(0x100 | d);
  } else {
    WRITE8BIT(d);
  }
}

void Arduino_MSPM0SPIDMA::write16(uint16_t d) {
  _data16.value = d;
  if (_dcPort == nullptr) // 9-bit SPI
  {
    WRITE9BIT(0x100 | _data16.msb);
    WRITE9BIT(0x100 | _data16.lsb);
  } else {
    WRITE8BIT(_data16.msb);
    WRITE8BIT(_data16.lsb);
  }
}

void Arduino_MSPM0SPIDMA::writeC8D8(uint8_t c, uint8_t d) {
  if (_dcPort == nullptr) // 9-bit SPI
  {
    WRITE9BIT(c);
    WRITE9BIT(0x100 | d);
  } else {
    if (_data_buf_bit_idx > 0) {
      flush_data_buf();
    }

    DC_LOW();

    _spi_tran_length = 8;
    _spi_tran_tx_data[0] = c;
    _spi_tran_use_txdata = true;

    POLL_START();
    POLL_END();

    DC_HIGH();

    _spi_tran_length = 8;
    _spi_tran_tx_data[0] = d;
    _spi_tran_use_txdata = true;

    POLL_START();
    POLL_END();
  }
}

void Arduino_MSPM0SPIDMA::writeC8D16(uint8_t c, uint16_t d) {
  if (_dcPort == nullptr) // 9-bit SPI
  {
    WRITE9BIT(c);
    _data16.value = d;
    WRITE9BIT(0x100 | _data16.msb);
    WRITE9BIT(0x100 | _data16.lsb);
  } else {
    if (_data_buf_bit_idx > 0) {
      flush_data_buf();
    }

    DC_LOW();

    _spi_tran_length = 8;
    _spi_tran_tx_data[0] = c;
    _spi_tran_use_txdata = true;

    POLL_START();
    POLL_END();

    DC_HIGH();

    _spi_tran_length = 16;
    _spi_tran_tx_data[0] = (d >> 8);
    _spi_tran_tx_data[1] = (d & 0xff);
    _spi_tran_use_txdata = true;

    POLL_START();
    POLL_END();
  }
}

void Arduino_MSPM0SPIDMA::writeC8D16D16(uint8_t c, uint16_t d1, uint16_t d2) {
  if (_dcPort == nullptr) // 9-bit SPI
  {
    WRITE9BIT(c);
    _data16.value = d1;
    WRITE9BIT(0x100 | _data16.msb);
    WRITE9BIT(0x100 | _data16.lsb);
    _data16.value = d2;
    WRITE9BIT(0x100 | _data16.msb);
    WRITE9BIT(0x100 | _data16.lsb);
  } else {
    if (_data_buf_bit_idx > 0) {
      flush_data_buf();
    }

    DC_LOW();

    _spi_tran_length = 8;
    _spi_tran_tx_data[0] = c;
    _spi_tran_use_txdata = true;

    POLL_START();
    POLL_END();

    DC_HIGH();

    _spi_tran_length = 32;
    _spi_tran_tx_data[0] = (d1 >> 8);
    _spi_tran_tx_data[1] = (d1 & 0xff);
    _spi_tran_tx_data[2] = (d2 >> 8);
    _spi_tran_tx_data[3] = (d2 & 0xff);
    _spi_tran_use_txdata = true;

    POLL_START();
    POLL_END();
  }
}

void Arduino_MSPM0SPIDMA::writeRepeat(uint16_t p, uint32_t len) {
  if (_data_buf_bit_idx > 0) {
    flush_data_buf();
  }

  if (_dcPort == nullptr) // 9-bit SPI
  {
    _data16.value = p;
    uint32_t hi = 0x100 | _data16.msb;
    uint32_t lo = 0x100 | _data16.lsb;
    uint16_t idx;
    uint8_t shift;
    uint16_t bufLen = (len <= 28) ? len : 28;
    int16_t xferLen;
    for (uint32_t t = 0; t < bufLen; t++) {
      idx = _data_buf_bit_idx >> 3;
      shift = (_data_buf_bit_idx % 8);
      if (shift) {
        _buffer[idx++] |= hi >> (shift + 1);
        _buffer[idx] = hi << (7 - shift);
      } else {
        _buffer[idx++] = hi >> 1;
        _buffer[idx] = hi << 7;
      }
      _data_buf_bit_idx += 9;

      idx = _data_buf_bit_idx >> 3;
      shift = (_data_buf_bit_idx % 8);
      if (shift) {
        _buffer[idx++] |= lo >> (shift + 1);
        _buffer[idx] = lo << (7 - shift);
      } else {
        _buffer[idx++] = lo >> 1;
        _buffer[idx] = lo << 7;
      }
      _data_buf_bit_idx += 9;
    }

    while (len) {
      xferLen = (bufLen < len) ? bufLen : len;
      _data_buf_bit_idx = xferLen * 18;

      _spi_tran_tx_buffer = (uint8_t *)_buffer32;
      _spi_tran_length = _data_buf_bit_idx;
      _spi_tran_use_txdata = false;

      POLL_START();
      POLL_END();

      len -= xferLen;
    }
  } else // 8-bit SPI
  {
    uint16_t bufLen = (len >= MSPM0SPIDMA_MAX_PIXELS_AT_ONCE) ? MSPM0SPIDMA_MAX_PIXELS_AT_ONCE : len;
    int16_t xferLen, l;
    uint32_t c32;
    MSB_32_16_16_SET(c32, p, p);

    l = (bufLen + 1) / 2;
    for (int16_t i = 0; i < l; i++) {
      _buffer32[i] = c32;
    }

    while (len) {
      xferLen = (bufLen <= len) ? bufLen : len;

      _spi_tran_tx_buffer = (uint8_t *)_buffer32;
      _spi_tran_length = xferLen << 4; // length in bits (xferLen * 16)
      _spi_tran_use_txdata = false;

      POLL_START();
      POLL_END();

      len -= xferLen;
    }
  }

  _data_buf_bit_idx = 0;
}
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

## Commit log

2026-04-29 Fix Switch namings
2026-04-29 Iron: use correct temperature for left_duty
2026-04-29 Set correct values for default setback/idle duty
    [configuration.h]
2026-04-29 seg7: Display the correct setpoint(heat_setpoint) when this one is changed
    [seg7.c]
2026-04-30 Acquisition: increase median filter size
2026-04-30 seg7: avoid flickering of the temperature around a value
    [seg7.c]
2026-05-08 Add fail-safe protection for misconnected tip
    Add a third measurement of the raw voltage on the TC pin and immediately
    shut down power if it exceeds a safety threshold, then enter the error state.
    [acquisition.c, adc.c, display.c]
2026-05-08 Iron: filter setpoint to avoid heat spikes at startup
    [configuration.h]
2026-05-08 seg7: don't use temperature if the tip don't have the TC
2026-05-08 seg7: use raw TC temperature in diag menu
2026-05-08 seg7: fix 0 temp display
    [seg7.c]
2026-05-08 heat: don't change state without tip
2026-05-08 heat: allow to toggle from setback to normal
2026-05-08 heat: don't change state when changing tip
2026-05-08 KTY: Use the temperature when there is not tip, and use fallback value in poor mode
    [configuration.h]
2026-05-08 seg7: Use only 2 last character of the tip name Restore real WXUP name in the code Don't use anymore W or M character: doesn't display correctly
    [seg7.c]
2026-05-08 seg7: SEG7 constant missing prefixes
    [seg7.c]
2026-05-10 Replace GPIOA with the associated pin PORT
    [acquisition.c, button.c, main.c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]
2026-05-10 calibration: add missing static const for kty_adc_table
    [calibration.c]
2026-05-19 st7789: Working screen without DMA
2026-05-19 st7789: Working DMA but using un-checked SRAM
2026-05-19 st7789: Working DMA by directly using parity checked SRAM and not the aliased one
2026-05-19 timer: add tick_ prefix
2026-05-19 st7789: Add missing screens
    [seg7.c, st7789.c, st7789_cpp.cpp]
2026-05-19 Arduino_GFX: Add build flags to strip unused code
2026-05-19 st7789: Improve the screen and fix view display
    [st7789.c]
2026-05-19 iron: Don't heat in standby or error state
2026-06-02 st7789/seg7: Fix race condition with CACHED_VALUE_GET and ACK: use new CACHED_VALUE_GET_ACK function
    [seg7.c, st7789.c]
2026-06-02 systick: Use a timer based on SYSOSC and MFCLK
    Using cortex systick seems really incorrect when PLL is enabled
2026-06-02 iron: increase heat factor and update idle duty default value accordingly
    Fix also left/right heat value
    [configuration.h]
2026-06-06 typo: filtred to filtered
2026-06-07 tip: debounce tip_type and reed_state. Avoiding transient value and misdetection of the tip_type during reed closing
    [acquisition.c]
2026-06-25 seg7: Fix display after setpoint changes
    [seg7.c]
2026-06-25 Add Simlations, 3D and PCBs
    [7SEG.kicad_sch, HSSwitch.kicad_sch, MCU.kicad_sch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]
